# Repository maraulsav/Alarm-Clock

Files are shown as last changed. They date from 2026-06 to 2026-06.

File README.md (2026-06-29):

# Alarm-Clock
Hello guysss, I have tried to make the alarm clock. But sadly it cannot work properly. I have tried everything that I can think of and the result is still like the picture below.. I have tried to documented every trial and error that I encounter in my Builder Journal.md file

As I have tried everything that possible for me like fixing  wiring diagra and code, fixing soldering issue, and yet its still not working. I think this project can be not working because of component issue, especially the TFT display because one of the things that I tried is to switch the power supply to 5V because I thought perhaps 3.3V is too low for this.. and it didnot work it jsut shut down completely at that trial (I think if thats the cause it can damage the internal component). Some suggestion for you guys is that dont be in rush to switch up your voltage supply because it may messed with the internal component signal. I think thats why the display that shown is gibberish.

but, I still wanted to said a special thanks to hackclub especially stasis that allow me to build the idea that I had. Thankss also for anyone of you guys that read this documentation.
Youtube documentation: https://youtu.be/MWKya9hIei4

Hii in this project I wanted to built an alarm clock that can display in real time (so it needed to connect to a wifi that can connect to my phone), also can gave sound to alert me, detect air quality and temperature and also I want it to function as a night lamp (I kind of scared of the dark wkwkwk).
Here is the look of my overal project: 


## Features : 
- Screen Display: TFT Display
- Humidity and Temperature Sensor: ENS160+AHT21 Sensor 
- Microcontroller: ESP32C3 Super Mini
- Type C charging module
- Speaker box
- LED lamp

## Hardware
Here I made the connection of the alarm clock, I dont use PCB because as I am not working in a tight space I think its kinda unecesary to use a PCB, and it can also cut cost anyway
Here's wiring diagram



## Case overview
In creating my case, I had measured the component and like designing the case so the connection wont lose, especially for the type c charging module
Below is the pincture of my case, there I plan to connect the two part (front and back) using the heat set insert

This is the front part of my case:


This is the back part of my case:



## Code Overview
This project used the Arduino IDE as the main platform to wrote the codes. 
The main feature of my code is:
- User can select menu / mode
- User can set the alarm
- The clock is connected to wifi from the phone so can update in real time
- The clock can also display the current air quality and temperature

## BOM
| Name | Purpose | Qty | Cost (USD) | Distributor |
|---|---|-----|---|---|
| M4 bolts with flat head | To connect the 3D printed parts | 1 | $0.93 | Tokopedia |
| Heat insert | To securely connect the 3D print | 1 | $3.78 | Tokopedia |
| Type-C charging module | Safely recharges single-cell lithium-ion batteries | 1 | $0.68 | Tokopedia |
| Switch | Toggle components on and off | 3 | $0.30 | Tokopedia |
| Jumper wire (male-to-male) | Connect one part to another | 2 | $1.41 | Tokopedia |
| LED COB Lamp | Light source for the clock (mirror lighting/night lamp) | 1 | $0.80 | Tokopedia |
| Speaker box (2x) | Producing sound | 1 | $3.04 | Tokopedia |
| 3.7 V Battery | Power supply | 2 | $1.61 | Tokopedia |
| ENS160 + AHT21 Sensor | Detect air quality and temperature | 1 | $5.04 | Tokopedia |
| ESP32-C3 | Main microcontroller | 1 | $2.00 | Tokopedia |
| TFT Display Module with Rotary Encoder | Display information and adjust the alarm | 1 | $19.15 | Tokopedia |

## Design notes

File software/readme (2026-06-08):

Hello this folder contain the code that you need..
This code is made in the arduino IDE platform

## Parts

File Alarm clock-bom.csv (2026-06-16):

Name | Purpose | Quantity | Total Cost (USD) | Link | Distributor
M4 builds with flat head | To connect the 3D printed parts | 1 | 0.93 | https://www.tokopedia.com/vsv/baut-kepala-rata-m4-stainless-steel-silverhawk-thin-flat-head-bolt-truss-head-bolt-1730804457732343381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 | Tokopedia
heat insert | To securely connect the 3D print | 1 | 3.78 | https://www.tokopedia.com/indocart/3d-printer-tools-compatible-brass-heat-insert-nuts-double-twill-knurled-injection-copper-thread-inserts-x-30pcs-17316560938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 | Tokopedia
Type C charging module | to safely recharges single-cell lithium-ion batteries | 1 | 0.68 | https://www.tokopedia.com/awallaptop/usb-type-c-mini-modul-charge-charger-type-c-5v-4-2v-3-7v-18650-lithium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 | Tokopedia
Switch | To toogle on and off to some compenent | 3 | 0.30 | https://www.tokopedia.com/indo-ware/ss12d00g3-toggle-switch-tiga-kaki-saklar-geser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 | Tokopedia
Jumper wire male to male | To connect one part to another | 2 | 1.41 | https://www.tokopedia.com/indo-ware/10pcs-dupont-cable-wire-male-to-male-20cm-kabel-jumper-breadboard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 | Tokopedia
LED COB Lamp | To light up the clock (Can be for mirror lighting or night lamp) | 1 | 0.80 | https://www.tokopedia.com/awallaptop/lampu-led-cob-strip-panjang-3-2v-3-3v-5w-putih-135x16mm-6w-6500k-1733418978478622489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 | Tokopedia
Speaker box (2x) | Producing sound | 1 | 3.04 | https://www.tokopedia.com/mirorim/speaker-box-kotak-mini-laptop-notebook-loudspeaker-4-8-ohm-1-5-2-5-3-w-1734262320455386169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 | Tokopedia
3.7 V Battery | Power supply | 2 | 1.61 | https://www.tokopedia.com/bsotactical/baterai-16340-rechargeable-cr123a-lr123a-3-7v-1300mah-batre-biru-1729527705306499143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 | Tokopedia
ENS160+AHT21 Sensor | Detecting Air Quality And Temperature | 1 | 5.04 | https://www.tokopedia.com/sellered/ens160-aht21-sensor-carbon-dioxide-co2-eco2-tvoc-air-quality-and-temperature-1731653358985839621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 | Tokopedia
ESP32-C3 | The main microcontroller | 1 | 2.00 | https://www.tokopedia.com/cncstorejogja/esp32-c3-esp32-c3-usbc-esp32c3-usb-c-super-mini-esp-32-c3-development-board-wifi-bluetooth-usb-c-iot-17313172792747960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 | Tokopedia
TFT Display module with rotary encoder | displaying stuff and for adjusting the alarm | 1 | 19.15 | https://www.tokopedia.com/electrogizmo/layar-tft-lcd-1-8-inch-2-4-inch-rotary-ener-ec11-modul-display-spi-st7735s-st7789-1-8-inch-tft-lcd-1734400539686176482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 | Tokopedia

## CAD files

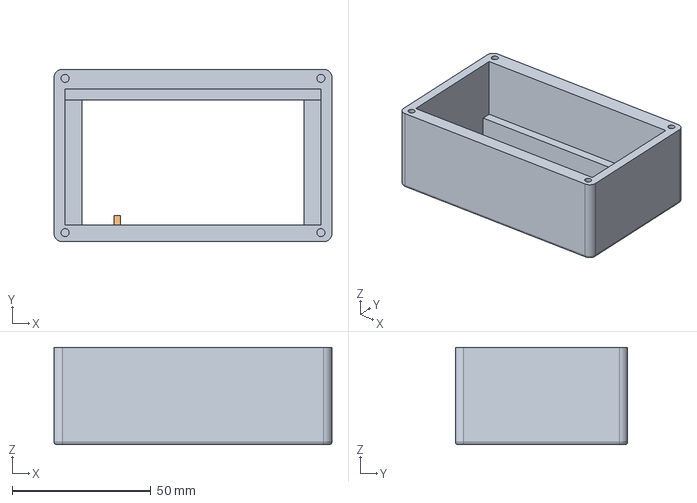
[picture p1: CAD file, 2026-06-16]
3D Print/Alarm Clock Front.step
100.0 x 62.0 x 35.0 mm

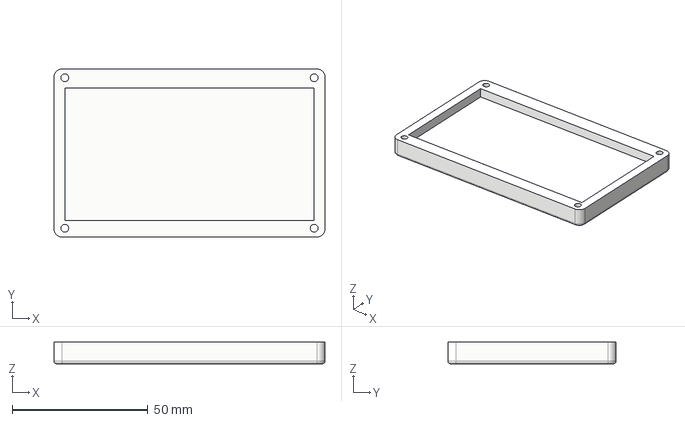
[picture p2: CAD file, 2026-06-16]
3D Print/Alarm clock back.step
100.0 x 62.0 x 8.00 mm

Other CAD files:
3D Print/Alarm Clock Front.f3z

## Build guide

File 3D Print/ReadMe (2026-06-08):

In this folder contain the case file of this alarm clock

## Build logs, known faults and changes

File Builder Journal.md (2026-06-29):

<!--
  This journal is auto generated by Stasis.
-->

# 6/29/2026 5 AM - Debugging things

_Time spent: 4.5h_

I think the hardest part when things go wrong at the device was searching what actually have gone wrong.. Like I first thought that this is a power supply issue, perhaps because a surge in power supply may ccause resetting signal on the TFT display so I connect  a capacitor near the 5V and GND. and.. it didnot work.. I mean the blue blinking ended but the TFT display didnot turn on also..

Then I think this might be a wiring issue because GPIO 8 is connected onw ith RGB blue, perhaps that's the problem, I connect the DC and CS pin to the 1 and 2 pin to test that out.. And it still didnot work. The TFT display cannot turn on.

Well perhaps its a soldering issue. So I solder again some of the TFT pin that kind of losen up. yeah the light emitted from TFT dislay became more stable. progress that good.

Then I started to think perhaps this is because of my code that did not work. I tried to kind of debugging it. It still only emitting blue dim light eventhough I demand it to emit red light. Below the code that I used to debugging it.


I am switching back to the normal codes. 
Then I getting suspicious with the schematic again. I tried to connect the ground to the head of the ESP32C3 display and. now the TFT emitting white light.



I inspect again the connection  perhaps some of the things are loosen up and disconnnecting.. Then.. I found the soldering. omg. yeah remember guys good soldering wire does important because I accidently connect the Reset and DC pin, which then I break that connection using clip

Yeah this sharp thing ( I dont know what is it called


So next I tried to power it up again.. andd.


It still didnt behave the way I wanted T-T. Like I. mean some progress because the TFT display now show some colorss but yet it stilll did not display the clock that I wantedd hwhwhwh.. Like I think I have checked everything and its not working. Really sorry guys but I cant continue because after fixing my code and schematic and even solder it still did not work and I got suspicious is this the component that broken. especially the TFT displya itseld.. I will update the new schematic and code

Thankyou for following my journey guys, and thankyou also for stasis that made this trial possible.






# 6/28/2026 12 PM - Udate on connection

_Time spent: 1h_

So, I got some suggestion that it can be because my esp32c3 keep resetting repeatedly because of current spike in TFT initialization. and they suggest me to connect the back light (blk) pin on TFT display to be connected with separate power supply from VCC. 

So I tried to connect the BLK pin to 5V power supply. When I tried to connect it, the blinking disappear and also the TFT display didnt turn on.



So I disconect it. and wire it up like my old schematic

I dont know what happen but somehow  there is a moment when my ESP32C3 didnt blink blue light but my TFT display still lighten up.. 

what actually happen.. I am confused



# 6/28/2026 10 AM - Connecting

_Time spent: 1.5h_

To simulate the connection first I used a breadboard.
the short conclusion..

It didn't work

Long one..
I dont know, its just got really weird because my ESP32C3 was blinking blue lights and at the same time my TFT display lighten up.. But I still dont know is this a connection problem or my TFT display is the one the broken..

Like I have checked the cables and all alright.. I think I wanna check up my soldering work later and maybe I also redo it againn



This is an example of my testing method



# 6/27/2026 10 AM - Soldering

_Time spent: 3h_

Hello guyss so my main component has come. anddd...
ITS TIME TO SOLDERR  YEAYYYY

alr, so what happen during soldering.. yeah, sadly my soldering wire that based on tin with flux core still on the way so I need to use my initialy one with lead wire..(Lead have higher melting temperature) 

If you want to bought soldering wire choose the one with tin as its main component and flux in its core.. Because it have lower melting temperature, easy to use. 

Lead is vulnerable to be like clogged up (like water dropplet in hydrophobic surface), because it also getting chill faster. That's why its really hardddddddddd to use

Look at my soldering result



It is not tidy enough..
And I can say the more time u spent with lead soldering wire the more stressed you will be wkwkkwkw.. Because after two hour my hands start trembling and yeah high heat also vulnerable to melt the component around. :" 

Yeah I don't know if this will worked out but I hope so



# 6/7/2026 2 AM - Code

_Time spent: 3.5h_

I always struggling with coding..
It drove me crazy yet I dont know if that's can work or not.

But anyway, here I manage to  complete the code


It took really long.. and well unfortunately my timelapse gone in the middle of me making this project..

But hum its alright
My suggestion is that to make this kind of code you need to determine first what all the menu that you need, like what kind of mod that you wanna have. 
Then you just need to create the functionss.



# 5/5/2026 11 PM - 3D casing

_Time spent: 2.5h_

Hi in this journal I made a 3D casing for my alarm
I made the casing to be a box because want it to be really efficient, not taking up many spaces.

So evaluating from my initial case on my mochi project. It is better to have something that hold up the display and the battery so it doesn't move freely.. 

In my case currently, I hold them up by creating different heights and something to make it stuck to the place

How my front case look like




And for my back case I just create a space for mirror and drill hole

This is the full look of the case with the front and the back parts joined






# 5/5/2026 9 AM - Schematic Design

_Time spent: 1.25h_

Schematics designn



Yea I think the most cofusing part is the connection to the TFT Display because yeah there are many pins that must be connected. Yea tricky I think

Oh by the ways here I assembly this in canva.. This is my first time using it for schematic design.. Because yea I usually use KICAD But because now I wanted to make an alarm clock whick dont need a PCB I want to save up the price..

I am actually confused on what software do I  use.. Because web like the Tinkercad dont have all the component that I need

Yea I dont recommend using canva like.. Ya know kinda rage baiting I think wwkkwkwk as the lines bro it is hard to get the lines parallel to the x or y axis...

 Okay thanks thats for today's journal



# 5/5/2026 4 AM - Brainstorming

_Time spent: 0.5h_

Hi hi guys so I will enter university soon.. and I need alarm clock. Like urgently because I am kinda nervous if I woke up late or things like that.. (I need to pray in early morning)

And as I think more.. Humm perhaps I can integrate another things to this alarm clock..

Think and thinking
I am kidna scared of the dark... Light would warm my heart up. and perhaps can help me to read book in late night

Then, perhaps later I need to do some make up so I will also integrate a mirror. 

In this step I also see the market of what kind of display that I will need.. As I want an alarm clock I would also need a display that can receive an input.. So, after some time thinking.. I chose the TFT LCD 1.8 Inch with rotary encoder

In this step I also design how will my alarm looks



Thiss, stay tuned!



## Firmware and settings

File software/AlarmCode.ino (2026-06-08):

#include "Adafruit_GFX.h"
#include "Adafruit_ST7735.h"
#include "Adafruit_AHTX0.h"
#include "ScioSense_ENS160.h"
#include <WiFi.h>

#define TFT_SCL 5
#define TFT_SDA 6
#define TFT_RES 7
#define TFT_DC 8
#define TFT_CS 9
#define TFT_A 10
#define TFT_B 20
#define TFT_Push 21
#define TFT_KO 0
#define ENS_SCL 2
#define ENS_SDA 1
#define LED 4
#define Buz 3

Adafruit_ST7735 tft = Adafruit_ST7735(TFT_CS, TFT_DC, TFT_RES);
Adafruit_AHTX0 aht;
ScioSense_ENS160 ens160(0x53);

#include <Fonts/FreeSerif18pt7b.h>
const char* ssid = "Dawn";
const char* password = "sasha101";


//Menu
enum UIMode{
  MODE_MENU = 0,
  MODE_CLOCK,
  MODE_ALARM,
  MODE_LED
};

UIMode currentMode = MODE_CLOCK;
int menuIndex = 0;
const int MENU_ITEMS = 3;

//The Environment Sensor Thingy Values
float curTemp = 0;
float curHum = 0;
float curTVOC = 0;
float curECO2 = 400;
unsigned long lastEnv = 0;

//Rotary Encoder
int lastEncA = HIGH;
int lastEncB = HIGH;
bool lastEncBtn = HIGH;
bool lastKey0 = HIGH;
unsigned long lastBtn = 0;

// Alarm
bool alarmEn = false;
int alarmHour = 7;
int alarmMinute = 0;
bool alarmRinging = false;
int alarmSlcField = 0;
int lastAlarmDay = -1;


bool buttonPress(int pin, bool &lastState){
  bool cur = digitalRead(pin);
  bool press = false;
  unsigned long now = millis();
  if (cur == LOW && lastState == HIGH && (now-lastBtn) > 150){
    press = true;
    lastBtn = now;
  }
  lastState = cur;
  return press;
}

void updateEnvSens(bool force = false){
  unsigned long now = millis();
  if (!force && (now - lastEnv) < 5000) return;
  lastEnv = now;

  sensors_event_t hum, temp;
  if (aht.getEvent(&hum, &temp)){
    curTemp = temp.temperature;
    curHum = hum.relative_humidity;
  }
  ens160.set_envdata(curTemp, curHum);
  ens160.measure();

  float newTVOC = ens160.getTVOC();
  float newCO2 = ens160.getCO2();

  if (newTVOC != 0xFFFF) curTVOC = newTVOC;
  if (newCO2  != 0xFFFF) curECO2 = newCO2;

  Serial.print("ENS160: TVOC=");
  Serial.print(curTVOC);
  Serial.print(" eCO2=");
  Serial.print(curCO2);
}


// WiFi & Time
void connectWiFiAndSyncTime(){
  
  tft.setTextSize(1);
  tft.setTextColor(ST7735_WHITE);
  tft.setCursor(10, 55);
  tft.print("Connecting to WiFi");
  WiFi.begin(ssid, password);

  const char* ntpServer = "pool.ntp.org";
  const long gmtOffset_sec = 7 * 3600;
  const int daylightOffset_sec = 0;

  int retry = 0;
  while (WiFi.status() != WL_CONNECTED && retry < 20){
    delay(300);
    tft.print(".");
    retry++;
  }

  if(WiFi.status() == WL_CONNECTED){
    configTime(gmtOffset_sec, daylightOffset_sec, ntpServer);
    tft.fillScreen(ST7735_BLACK); 
    tft.setTextColor(ST7735_WHITE);
    tft.setCursor(10, 55);
    tft.print("Syncing time...");
    delay(800);
  } else{
    tft.fillScreen(ST7735_BLACK);
    tft.setTextColor(ST7735_RED);
    tft.setCursor(10, 55);
    tft.print("WiFi Failed");
    delay(1200);
  }
}

String getTime(char type){
  struct tm timeinfo;
  if (!getLocalTime(&timeinfo)) return "--";
  char buf[8];
  if (type == 'H') strftime(buf, sizeof(buf), "%H", &timeinfo);
  else if (type == 'M') strftime(buf, sizeof(buf), "%M", &timeinfo);
  else if (type == 'S') strftime(buf, sizeof(buf), "%S", &timeinfo);
  else return "--";
  return String(buf);
}

int readEncoderStep() {
  int a = digitalRead(TFT_A);
  int b = digitalRead(TFT_B);
  int step = 0;
  if (a != lastEncA) {
    if (a == LOW) {
      step = (b == HIGH) ? 1 : -1;
    }
  }
  lastEncA = a;
  lastEncB = b;
  return step;
}

bool checkButtonPressed(int pin, bool &lastState) {
  return buttonPress(pin, lastState);
}


// MENU
void drawMenu(){
  tft.fillScreen(ST7735_BLACK);
  tft.setTextSize(1);
  tft.setTextColor(ST7735_WHITE);
  tft.setCursor(10, 10);
  tft.print("SELECT MODE");

  const char* items[MENU_ITEMS] = {
    "CLOCK",
    "ALARM",
    "LED"
  };

  for (int i = 0; i < MENU_ITEMS; i++){
    int y = 32 + i * 18;
    if (i == menuIndex) {
      tft.fillRect(6, y-2, 148, 14, ST7735_YELLOW);
      tft.setTextColor(ST7735_BLACK);
    } 
    else{
      tft.fillRect(6, y-2, 148,14, ST7735_BLACK);
      tft.setTextColor(ST7735_WHITE);
    }
    tft.setCursor(12, y);
    tft.print(items[i]);
  } 
}



// LED

void drawLedMenu(bool fullRedraw) {
if (fullRedraw) tft.fillScreen(ST7735_BLACK);
  tft.setTextSize(1);
  tft.setTextColor(ST7735_CYAN);
  tft.setCursor(20, 10);
  tft.print("LED CONTROL");

  tft.fillRect(5, 30, 150, 40, ST7735_BLACK);
  tft.setTextColor(ledOption == 0 ? ST7735_YELLOW : ST7735_WHITE);
  tft.setCursor(10, 33);
  tft.print(ledOption == 0 ? "> Turn ON" : "  Turn ON");

  tft.setTextColor(ledOption == 1 ? ST7735_YELLOW : ST7735_WHITE);
  tft.setCursor(10, 50);
  tft.print(ledOption == 1 ? "> Turn OFF" : "  Turn OFF");

  tft.setTextColor(ST7735_GREEN);
  tft.setCursor(10, 75);
  tft.print("LED: ");
  tft.print(ledState ? "ON " : "OFF");
}

void handleButton() {

  if (currentMenu == LED) {

    if (ledOption == 0) {
      digitalWrite(LED_PIN, HIGH);
      ledState = true;
    }

    else if (ledOption == 1) {
      digitalWrite(LED_PIN, LOW);
      ledState = false;
    }
  }
}

//Alarm
void checkAlarmTrigger(){
  if (!alarmEn || alarmRinging) return;
  struct tm timeinfo;  
  if (!getLocalTime(&timeinfo)) return;
  if (timeinfo.tm_hour == alarmHour &&
      timeinfo.tm_min == alarmMinute &&
      timeinfo.tm_sec == 0 &&
      timeinfo.tm_mday != lastAlarmDay) {
    alarmRinging = true;
    lastAlarmDay = timeinfo.tm_mday;
    currentMode = MODE_ALARM;
  }
}

void updateAlertStateAndLED(){
  static unsigned long lastBlink = 0;
  static bool blinkState = false;
  if (alarmRinging){
    if (millis() - lastBlink > 300){
      lastBlink = millis();
      blinkState = !blinkState;
      digitalWrite(LED, blinkState ? HIGH : LOW);
    }
  } else {
    digitalWrite(LED, LOW);
  }
}

void setup() {


  Serial.begin(115200);
  delay (1500);

  pinMode(TFT_A, INPUT_PULLUP);
  pinMode(TFT_B, INPUT_PULLUP);
  pinMode(TFT_Push, INPUT_PULLUP);
  pinMode(TFT_KO, INPUT_PULLUP);

  pinMode(LED, OUTPUT);
  pinMode(Buz, OUTPUT);
  digitalWrite(LED, LOW);

  Wire.begin(ENS_SDA, ENS_SCL);
  SPI.begin(TFT_SCL, -1, TFT_SDA, TFT_CS);

  tft.initR(INITR_BLACKTAB);
  tft.fillScreen(ST7735_BLACK);
  tft.setRotation(1);
  tft.setTextWrap(true);

  connectWifiAndSyncTime();
  if(!aht.begin()) Serial.println("AHT not found TRY AGAIN");
  if(!ens160.begin()) Serial.println("ENS160 FAILED TRY AGAIN");
  else ens160.setMode(ENS160_OPMODE_STD);

  updateEnvSens(true);

  initClockStaticUI();
  prevTimeStr = "";
  drawClockTime(getTimeStr('H'), getTimeStr('M'), getTimeStr('S'));
  drawEnvDynamic(curTemp, curHum curTVOC, curECO2);
}

void loop() {
  // put your main code here, to run repeatedly:
  static unsigned long lastWifiCheck = 0;
  if (millis() - lastWifiCheck > 10000){
    lastWifiCheck = millis();
    if (WiFi.status() != WL_CONNECTED){
      WiFi.begin(ssid, password);
    }
  }
  
  int encStep = readEncoderStep();
  bool encPress = checkButtonPressed(ENC_BTN_PIN, lastEncBtn);
  bool k0Pressed = checkButtonPressed(KEY0_PIN, lastKey0);

  checkAlarmTrigger();
  updateAlertStateAndLED();

  switch (currentMode){
    case MODE_MENU: {
      if (encStep != 0) {
        menuIndex += encStep;
        if (menuIndex < 0 ) menuIndex = MENU_ITEMS - 1
        if (menuIndex >= MENU_ITEMS) menuIndex = 0;
        drawMenu();
      }
      if (encPressed){
        if (menuIndex == 0){
          currentMode = MODE_CLOCK;
          initClockStaticUI();
          prevTimeStr = "";
          updateEnvSens(true);
          drawClockTime (getTimeStr ('H'), getTimeStr('M'), getTimeStr ('S'));
          drawEnvDynamic(curTemp, curHum, curTVOC, curECO2);
        }
        else if(menuIndex == 1){
          currentMode = MODE_ALARM;
          alarmSelectedField = 0;
          drawAlarmScreen(true);
        }
        else if (menuIndex == 2){
          currentMode = MODE_LED;
          drawLEDMenu(true);
        }
      }
      break
    }
    case MODE_CLOCK: {
      struct tm timinfo;
      if(getLocalTime(&timinfo)){
        int sec = timinfo.tm_sec;
        if (sec != prevSecond){
          prevSecond = sec;
          drawClockTime(getTimeStr('H'), getTimeStr('M'), getTimeStr('S'));
          if(sec% 5 == 0){
            updateEnvSensors(true);
            drawEnvDynamic(curTemp, curHum, curTVOC, curECO2);

          }
        }
      }
      if (k0Pressed){
        currentMode = MODE_MENU;
        drawMenu();
      }
      break
    }

    case MODE_ALARM: {
      if (alarmRInging) {
        static unsigned long lastBeep = 0;
        if (millis()- lastBeep > 1000){
          lastBeep = millis();
          tone(Buz, 2000, 400);
        }
        if (encPressed || k0Pressed) {
          alarmRinging = false;
          lastAlarmDayTrigged = -1;
          noTone(Buz);
          drawAlarmScreen(true);
        }
        break;
      }
      bool changed = false;
      if (encStep != 0) {
        if (alarmSelectedField == 0){
          if(encStep > 0) alarmHour = (alarmHour + 1) % 24;
          else alarmHour = (alarmHour+23) % 24;
          changed = true;
        }
        else if (alarmSelectedField == 1) {
          if (encStep > 0) alarmMinute = (alarmMinute + 1) % 60;
          else alarmMinute = (alarmMinute + 59) % 60;
          changed = true;
        }
        else if (alarmSelectedField == 2){
          alarmEnabled = !alarmEnabled;
          changed = true;
        }
        if(changed){
          lastAlarmDay = -1
        }
      }
      if (encPressed){
        alarmSelectedField = (alarmSelectedField + 1)% 3;
        changed = true;
      }
    }
    if (encPressed){
      alarmSelectedField = (alarmSelectedField + 1) % 3 ;
      changed = true;
    }
    if (k0Pressed){
      currentMode = MODE_MENU;
      drawMenu();
      break
    }
    if(changed){
      drawAlarmScreen(false);
      drawAlarmIcon();
    }

    case MODE_LED: {
      if (encStep != 0){
        ledOption += encStep;
        if (ledOption < 0) ledOption = 1;
        if (ledOption > 1) ledOption = 0;
        drawLEDMenu(false);
      }
      if (encPress) {
        if (ledOption == 0){
          ledState = true;
          digitalWrite(LED, HIGH);
        } else{
          ledState = false;
          digitalWrite(LED, LOW);
        }
        drawLEDMenu(false);
      }
      if (k0Press){
        currentMode = MODE_MENU;
        drawMenu();
      }
      break;
    }
  }
  break;
}

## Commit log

2026-06-29 Wiring Diagram Update
2026-06-29 Rename Screenshot 2026-06-29 at 13.42.09.png to Clock Wiring Diagram
